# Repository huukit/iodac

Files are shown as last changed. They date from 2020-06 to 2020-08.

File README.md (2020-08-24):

# iodac
The Proximia iodac is an isolated Digital-in to 0-10V out controller for applications that require conversion from a digital signal to a analog voltage output.

Such application are for example AC-blowers that usually need a 0-10V input but the HMI is a button interface.

Features:
* 5V input voltage.
* Fully isolated power supply.
* 5 fully isolated low-active inputs. (5V)
* Each input can be configured to a specific output voltage.
* 1 0-10V output. (25mA max load)

The operating mode currently follows the input active with the highest number input having the highest priority, but
the source can be modified for operation where the output will hold the last value. (Pulsed input signal).

# Schematic

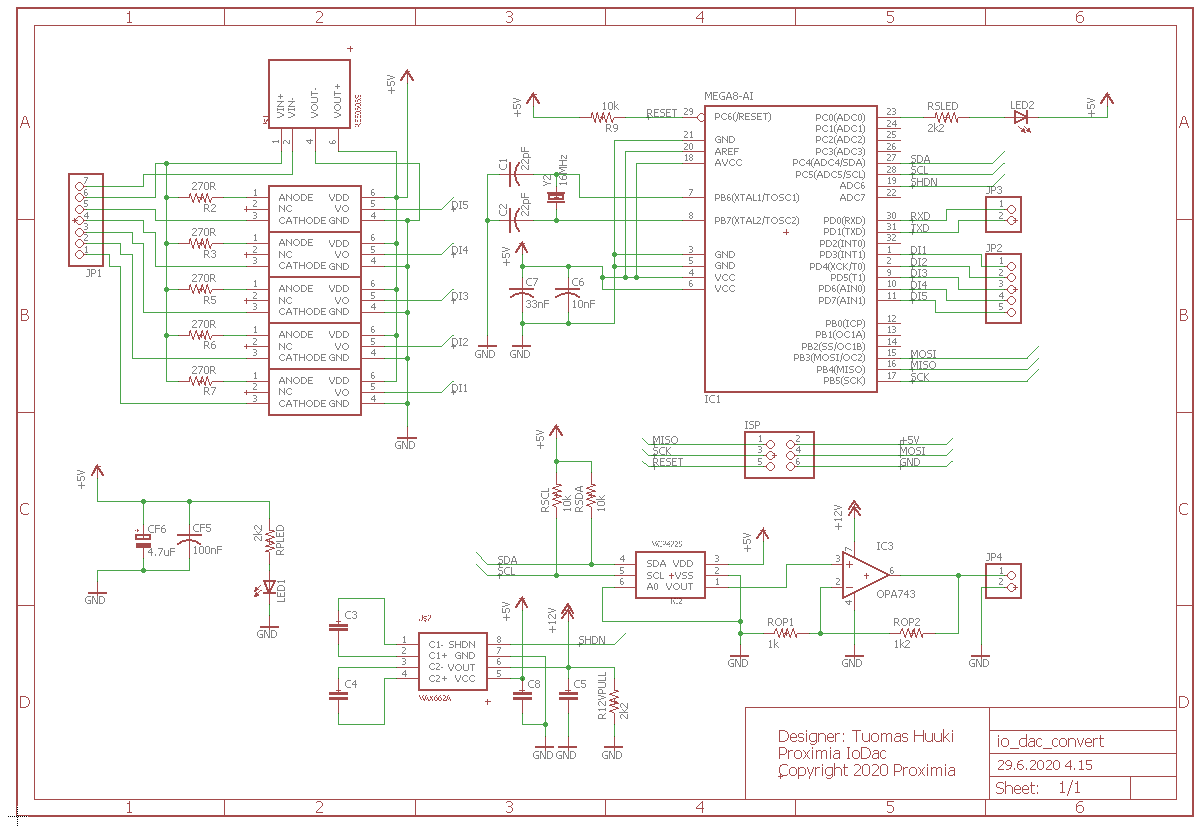
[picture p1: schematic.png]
Schematic


## Pins
### JP1
Inputs 1-5, VCC (+5V, GND) .
### JP2
Debug header for isolated inputs.
### JP3
0-10V output adjust pins.
### JP4
0-10V output.

# Connection example

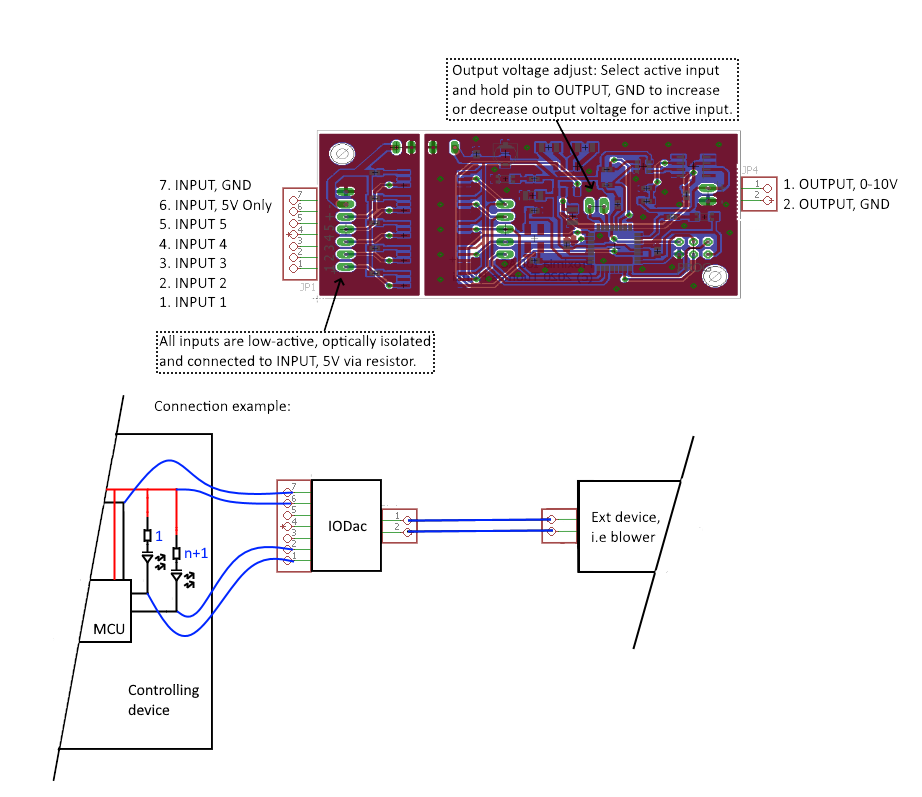
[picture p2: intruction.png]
Instructions


## Connecting
1. Locate the GND and +5V supply lines in the controlling device.
1. Connect the GND line to JP1.7 and +5V to JP1.6.
1. Locate the outputs (buttons or leds) on the controlling device, and make sure they are low-active.
1. Connect the lowest priority output (i.e. 1) to JP1.1 and then the rest of the outputs as required in order. 
Remember, that the highest number input will have priority. That is, if input 3 is active, input 1 will be ignored.
 
## Adjusting output voltage
1. Connect a multimeter to the output (JP4.1 + JP4.2). Remember to use the correct GND for measurements!
1. Activete the input that is to be adjusted.
1. Optionally connect a button between JP3.1 <-> JP4.2 and JP3.2 <-> JP4.2. A simple wire to toggle the pins can also be used.
1. Measure the output while adjusting the voltage with the buttons (or use the wire).
1. Repeat for each active input.

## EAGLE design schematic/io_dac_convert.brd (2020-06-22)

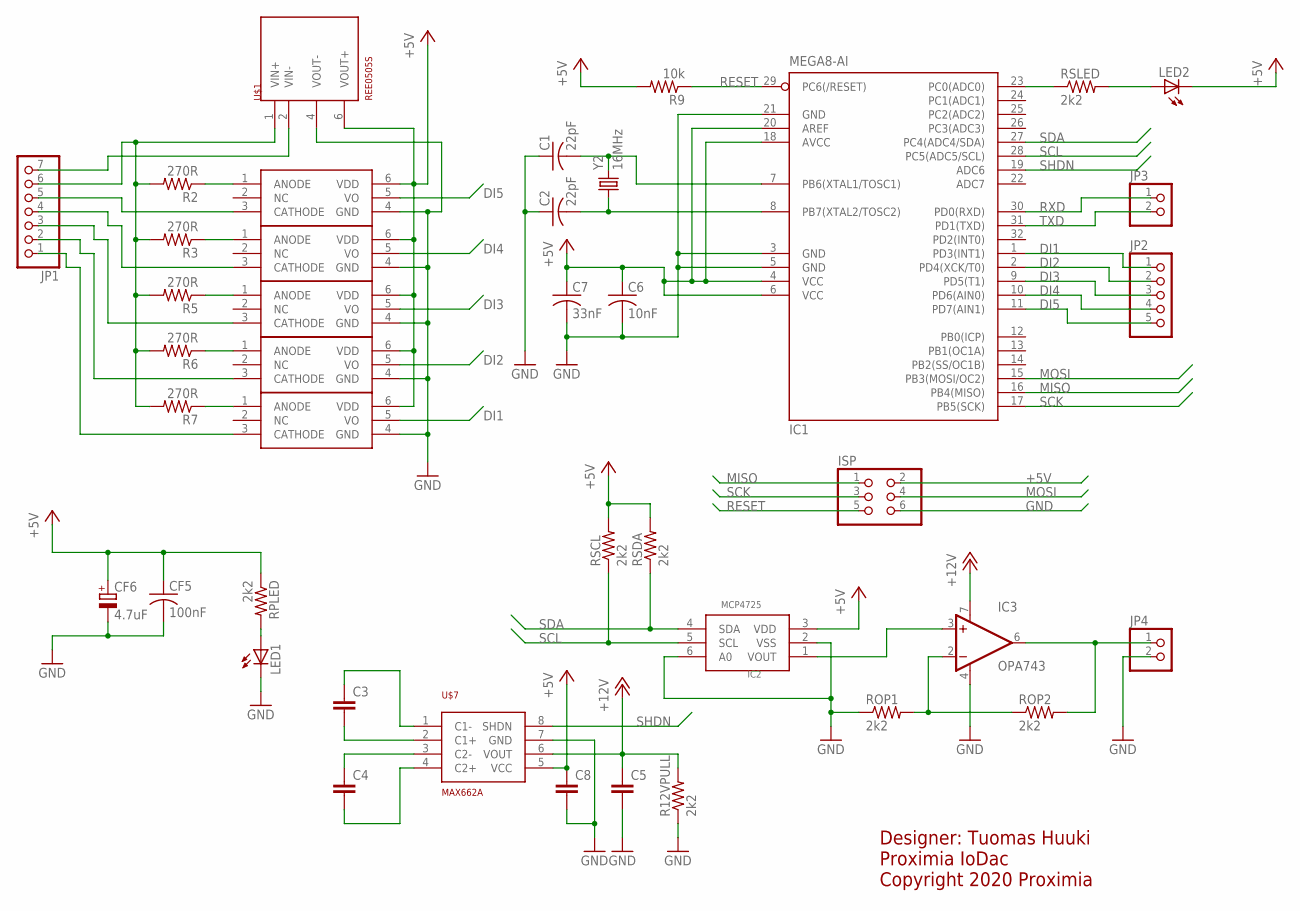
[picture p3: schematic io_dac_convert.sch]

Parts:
C1, C2: 22pF; C0603
C3, C4, C5, C8: C-EUC1206; C1206
C6: 10nF; C0603
C7: 33nF; C0603
CF5: 100nF; C0603
CF6: 4.7uF; PANASONIC_B
IC1: MEGA8-AI; TQFP32-08
IC2: MCP4725; SOT23-6
IC3: OPA743; SO08
ISP: PINHD-2X3; 2X03
JP1: PINHD-1X7; 1X07
JP2: PINHD-1X5; 1X05
JP3, JP4: PINHD-1X2; 1X02
LED1, LED2: LEDSML1206; SML1206
R2, R3, R5, R6, R7: 270R; R0603
R9: 10k; R0603
R12VPULL: 2k2; R0603
ROP1, ROP2: 2k2; R0603
RPLED: 2k2; R0603
RSCL: 2k2; R0603
RSDA: 2k2; R0603
RSLED: 2k2; R0603
U$1: REE0505S; SIP-6
U$2, U$3, U$4, U$5, U$6: SI8710; SDIP-6
U$7: MAX662A; SO8
Y2: 16MHz; CRYSTAL-SMD-5X3

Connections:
+5V: C6.1, C7.1, C8.1, CF5.1, CF6.+, IC1.4 (VCC), IC1.6 (VCC), IC1.18 (AVCC), IC1.20 (AREF), IC2.3 (VDD), ISP.2, LED2.C, R9.2, RPLED.1, RSCL.2, RSDA.2, U$1.6 (VOUT+), U$2.6 (VDD), U$3.6 (VDD), U$4.6 (VDD), U$5.6 (VDD), U$6.6 (VDD), U$7.5 (VCC)
+12V: C5.1, IC3.7 (V+), R12VPULL.2, U$7.6 (VOUT)
DI1: IC1.1 (PD3(INT1)), JP2.1, U$6.5 (VO)
DI2: IC1.2 (PD4(XCK/T0)), JP2.2, U$5.5 (VO)
DI3: IC1.9 (PD5(T1)), JP2.3, U$4.5 (VO)
DI4: IC1.10 (PD6(AIN0)), JP2.4, U$3.5 (VO)
DI5: IC1.11 (PD7(AIN1)), JP2.5, U$2.5 (VO)
GND: C1.1, C2.1, C5.2, C6.2, C7.2, C8.2, CF5.2, CF6.-, IC1.3 (GND), IC1.5 (GND), IC1.21 (GND), IC2.2 (VSS), IC2.6 (A0), IC3.4 (V-), ISP.6, JP4.2, LED1.C, R12VPULL.1, ROP1.1, U$1.4 (VOUT-), U$2.4 (GND), U$3.4 (GND), U$4.4 (GND), U$5.4 (GND), U$6.4 (GND), U$7.7 (GND)
GND_EXT: JP1.7, U$1.2 (VIN-)
MISO: IC1.16 (PB4(MISO)), ISP.1
MOSI: IC1.15 (PB3(MOSI/OC2)), ISP.4
unnamed: LED1.A, RPLED.2
unnamed: IC1.23 (PC0(ADC0)), RSLED.1
unnamed: JP1.6, R2.2, R3.2, R5.2, R6.2, R7.2, U$1.1 (VIN+)
unnamed: R2.1, U$2.1 (ANODE)
unnamed: JP1.5, U$2.3 (CATHODE)
unnamed: R3.1, U$3.1 (ANODE)
unnamed: R5.1, U$4.1 (ANODE)
unnamed: R6.1, U$5.1 (ANODE)
unnamed: R7.1, U$6.1 (ANODE)
unnamed: JP1.4, U$3.3 (CATHODE)
unnamed: JP1.3, U$4.3 (CATHODE)
unnamed: JP1.2, U$5.3 (CATHODE)
unnamed: JP1.1, U$6.3 (CATHODE)
unnamed: C2.2, IC1.8 (PB7(XTAL2/TOSC2)), Y2.1
unnamed: C1.2, IC1.7 (PB6(XTAL1/TOSC1)), Y2.3 (2)
unnamed: C3.2, U$7.2 (C1+)
unnamed: IC2.1 (VOUT), IC3.3 (+IN)
unnamed: IC3.6 (OUT), JP4.1, ROP2.2
unnamed: IC3.2 (-IN), ROP1.2, ROP2.1
unnamed: C3.1, U$7.1 (C1-)
unnamed: LED2.A, RSLED.2
unnamed: C4.1, U$7.3 (C2-)
unnamed: C4.2, U$7.4 (C2+)
RESET: IC1.29 (PC6(/RESET)), ISP.5, R9.1
RXD: IC1.30 (PD0(RXD)), JP3.1
SCK: IC1.17 (PB5(SCK)), ISP.3
SCL: IC1.28 (PC5(ADC5/SCL)), IC2.5 (SCL), RSCL.1
SDA: IC1.27 (PC4(ADC4/SDA)), IC2.4 (SDA), RSDA.1
SHDN: IC1.19 (ADC6), U$7.8 (SHDN)
TXD: IC1.31 (PD1(TXD)), JP3.2

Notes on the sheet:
Designer: Tuomas Huuki Proximia IoDac Copyright 2020 Proximia

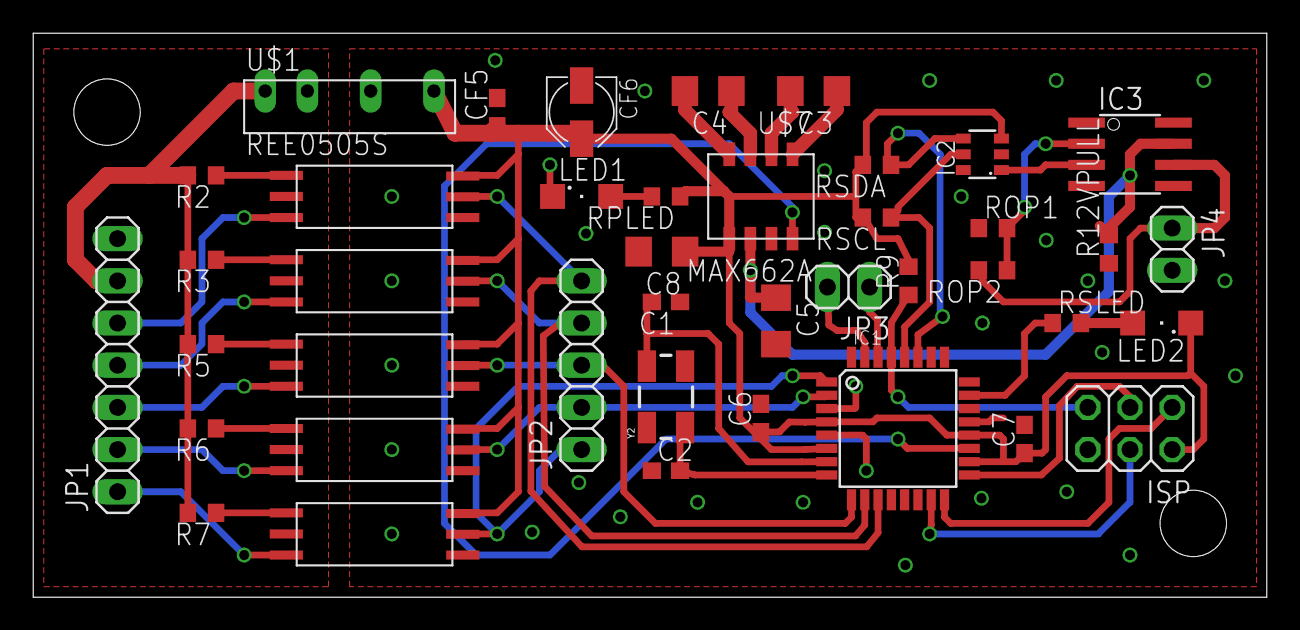
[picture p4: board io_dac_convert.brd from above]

Board: 2 copper layers, 74.3 x 34.0 mm, 41 parts (0 on the bottom side), 41 nets.

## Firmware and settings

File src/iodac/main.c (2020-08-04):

#define F_CPU 16000000UL

#include <util/delay.h>
#include <avr/io.h>
#include <avr/eeprom.h>
#include <stdbool.h>

#include "i2c.h"

#define ADC_I2C_ADDR 0b1100000
#define I2C_READ_CMD_BIT 1
#define I2C_WRITE_CMD_BIT 0

#define DACMAX 4095

int16_t dacreg = 0;
int16_t increment = 0;
uint8_t write_done = true;

int16_t step1 EEMEM;
int16_t step2 EEMEM;
int16_t step3 EEMEM;
int16_t step4 EEMEM;
int16_t step5 EEMEM;

void delay_ms(int ms)
{
	while (ms > 0)
	{
		_delay_ms(1);
		--ms;
	}
}

/* IoDAC, (c) 2020 Tuomas Huuki, proximia.fi */

void check_limits_and_set(int16_t *value, int16_t increment){
	if((*value + increment) > DACMAX) *value = DACMAX;
	else if((*value + increment) < 0) *value = 0;
	else *value += increment;
}

int main() 
{
	// Set led and i2c-pins as output.
	DDRC |= ((1 << PINC0) | (1 << PINC4) | (1 << PINC5));
	
	// Level inputs as inputs with pullups.
	DDRD &= ~((1 << PIND3) | (1 << PIND4) | (1 << PIND5) | (1 << PIND6) | (1 << PIND7));
	PORTD |= ((1 << PIND3) | (1 << PIND4) | (1 << PIND5) | (1 << PIND6) | (1 << PIND7));
	
	// Configuration ports
	DDRD &= ~((1 << PIND0) | (1 << PIND1));
	PORTD |= ((1 << PIND0) | (1 << PIND1));
	
	PORTC &= ~(1 << PINC0);
	
	step1 = eeprom_read_word(&step1);
	step2 = eeprom_read_word(&step2);
	step3 = eeprom_read_word(&step3);
	step4 = eeprom_read_word(&step4);
	step5 = eeprom_read_word(&step5);
	
    I2C_Init();

    while(1)
    {
		// Increase or decrease output.
		increment = 0;
		
		if(!(PIND & (1 << PIND0))){
			increment += 20;
			write_done = false;
			_delay_ms(100);
		}
		if(!(PIND & (1 << PIND1))){
			increment -= 20;
			write_done = false;
			_delay_ms(100);
		}
		
		// Set new value and set dac.
		if(!(PIND & (1 << PIND7))){
			check_limits_and_set(&step5, increment);
			dacreg = step5;
		}
		else if(!(PIND & (1 << PIND6))){
			check_limits_and_set(&step4, increment);
			dacreg = step4;
		}
		else if(!(PIND & (1 << PIND5))){
			check_limits_and_set(&step3, increment);
			dacreg = step3;
		}
		else if(!(PIND & (1 << PIND4))){
			check_limits_and_set(&step2, increment);
			dacreg = step2;
		}
		else if(!(PIND & (1 << PIND3))){
			check_limits_and_set(&step1, increment);
			dacreg = step1;
		}
		else{
			dacreg = 0;
		}
		
		if(increment == 0 && write_done == false){
			write_done = true;
			eeprom_write_word(&step1, step1);
			eeprom_write_word(&step2, step2);
			eeprom_write_word(&step3, step3);
			eeprom_write_word(&step4, step4);
			eeprom_write_word(&step5, step5);
		}	
		
		I2C_Start();
		I2C_Write((ADC_I2C_ADDR << 1) | I2C_WRITE_CMD_BIT);
		I2C_Write(0x0F & (uint8_t)(dacreg >> 8));
		I2C_Write((uint8_t)dacreg);
		I2C_Stop();
						
		PORTC &= ~(1 << PINC0);
		delay_ms(100 * (dacreg / 500 + 1));
		PORTC |= (1 << PINC0);
		delay_ms(100 * (dacreg / 500 + 1));
    }
    return (0);
}

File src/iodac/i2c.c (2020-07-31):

#include <avr/io.h>
#include <util/delay.h>
#include "i2c.h"

void I2C_Init()
{
    TWSR=0x00; 
    TWBR=0x46; // SCL frequency is 50K with 16Mhz
    TWCR=0x04; // Enable I2c.
}

void I2C_Start()
{
    TWCR = ((1<<TWINT) | (1<<TWSTA) | (1<<TWEN));
    while (!(TWCR & (1<<TWINT)));
}

void I2C_Stop(void)
{
    TWCR = ((1<< TWINT) | (1<<TWEN) | (1<<TWSTO));
	_delay_us(100) ; 
}

void I2C_Write(uint8_t v_i2cData_u8)
{
    TWDR = v_i2cData_u8 ;
    TWCR = ((1<< TWINT) | (1<<TWEN));
    while (!(TWCR & (1 <<TWINT)));
}

uint8_t I2C_Read(uint8_t v_ackOption_u8)
{
    TWCR = ((1<< TWINT) | (1<<TWEN) | (v_ackOption_u8<<TWEA));
    while ( !(TWCR & (1 <<TWINT)));
    return TWDR;
}

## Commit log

2020-06-22 Initial schematics for I/O converter
    [io_dac_convert.brd, io_dac_convert.sch]
2020-06-26 Moved schematics to correct dir.
    [io_dac_convert.brd, io_dac_convert.sch]
2020-07-31 Adding source code for board.
2020-08-04 Adding functionality to configure each output voltage separately.
2020-08-24 Added instructional picture and picture of schematic.
2020-08-24 Updated readme with instructions on connecting the device.

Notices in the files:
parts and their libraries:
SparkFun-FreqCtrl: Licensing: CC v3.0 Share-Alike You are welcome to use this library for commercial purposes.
